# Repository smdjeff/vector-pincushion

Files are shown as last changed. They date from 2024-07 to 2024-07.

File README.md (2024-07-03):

# vector-pincushion

## Allows CRT swaps between various vector game boards and deflection boards. 

Finding tubes for vector arcade displays is difficult and being able to mix and match deflection boards, TV CRTs and arcade PCBs is becoming a necessity. Some arcade games relied on an exact combination of tube shape, yoke, and game board to correctly display.  There may be analog corrections on either the arcade PCB or the deflection board or even the CRT yoke and neck. The Amplifone deflection boards contain no corrections, so when used with a Wells Gardner game PCB adding a correction board is a necessity to add the missing circuity. Tempest PCBs lacked the adjustments as did Sega vectors, but more advanced games like Major Havoc and Star Wars had them on the game boards rather than the deflection boards.

This board allows correction or decorrection as required depending on what you have combined.

### Linearity adjustment 
applies the function _X = X * k_ and _Y = Y * k_ allowing calibration of straightness in diagonally drawn vectors. When set to expansion mode, the correction will cause lines to be drawn further and further outward from the center. When set to shrink mode, the correction will cause lines to be drawn closer and closer the further they are from the center.

### Pincushion correction 
applies the function _X = X * k * Y_ and _Y = Y * k * X_ allowing for each axis to be drawn further or closer toward the center depending on the *opposite* axis distance from center.

## Features

* Barreling correction mode
* Pincushion correction mode
* Linearity shrinking mode
* Linearity expansion mode
* Performs geometric distortion math in analog circuity
* Single 5V supply
* No unobtanium voltage dependent resistor required
* No unobtanium MC1495 analog multipler required
* All new design around the AD633 analog multipler typically used in very high end audio equipment.
* Supports 2x faster speed than orignal when used with TI-H 5.25MHz bandwidth amplifiers.

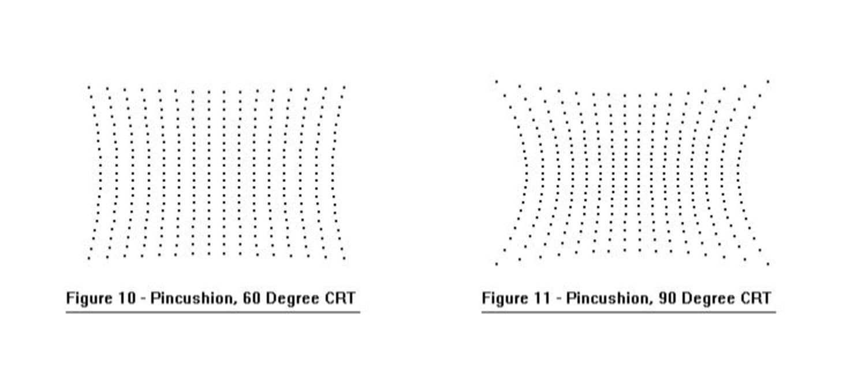
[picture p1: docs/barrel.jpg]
Barrel and Pincushion

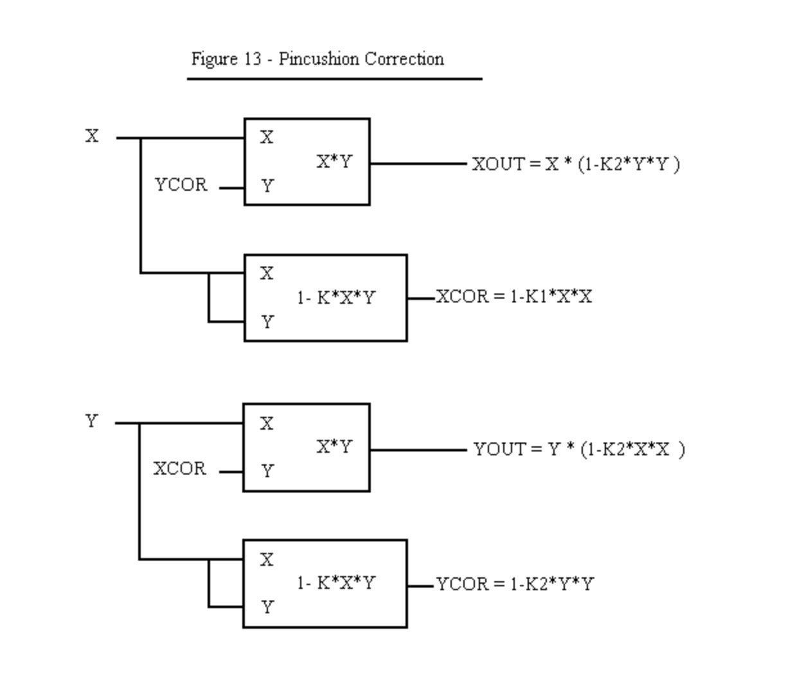
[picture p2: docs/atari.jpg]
Atari Math

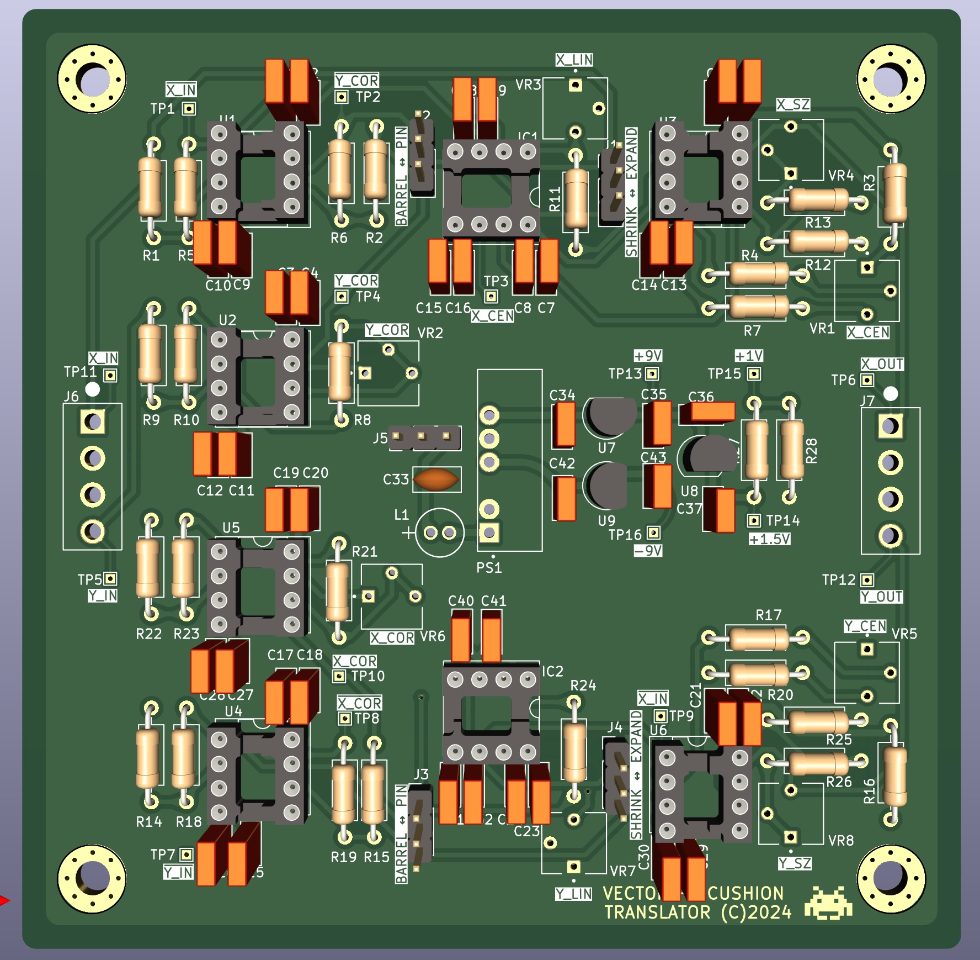
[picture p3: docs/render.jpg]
Board Render


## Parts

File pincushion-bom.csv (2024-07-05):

Qty | Reference(s) | Value | Part Number
20 | C1, C3, C5, C7, C9, C11, C13, C15, C17, C19, C21, C23, C25, C27, C29, C31, C35, C39, C41, C43 | .1uF | K104K15X7RF5TL2
18 | C2, C4, C6, C8, C10, C12, C14, C16, C18, C20, C22, C24, C26, C28, C30, C32, C38, C40 | .01uF | K103K10X7RF53L2
1 | C33 | 10uF CER | FG16X7R1E106KRT06
2 | C34, C42 | .33uF | FA24X7R1H334KNU06
2 | C36, C37 | 1uF | FG28X7R1E105KRT00
2 | IC1, IC2 | AD633JN | AD633JN
5 | J1, J2, J3, J4, J5 | Conn_01x03_Male | DNP
2 | J6, J7 | 640385-4 | WM50027-04-ND
1 | L1 | 22uH | 11R223C
1 | PS1 | RD-0512D | RD-0512D
1 | R28 | 100k 0.1% | RN55E1003BRE6
12 | R1, R2, R4, R5, R6, R9, R14, R15, R17, R18, R19, R22 | 100k 1% | MFR-25FRF52-100K
4 | R3, R7, R16, R20 | 1M | MF0207FRE52-1M
6 | R8, R10, R12, R21, R23, R25 | 10k | MFR-25FRF52-10K
3 | R11, R24, R27 | 50k 0.1% | RN55C5002BB14
2 | R13, R26 | 70k | RN55D7002FB14
6 | U1, U2, U3, U4, U5, U6 | TL082 | TL082CP
1 | U7 | DI78L09ZAB | DI78L09ZAB
1 | U8 | MCP1702-1502E/TO | MCP1702-1502E/TO
1 | U9 | DI79L09ZAB | DI79L09ZAB
2 | VR1, VR5 | 100k | 3362P-1-104LF
2 | VR2, VR6 | 10k | 3362P-1-103LF
4 | VR3, VR4, VR7, VR8 | 20k | 3362P-1-203LF

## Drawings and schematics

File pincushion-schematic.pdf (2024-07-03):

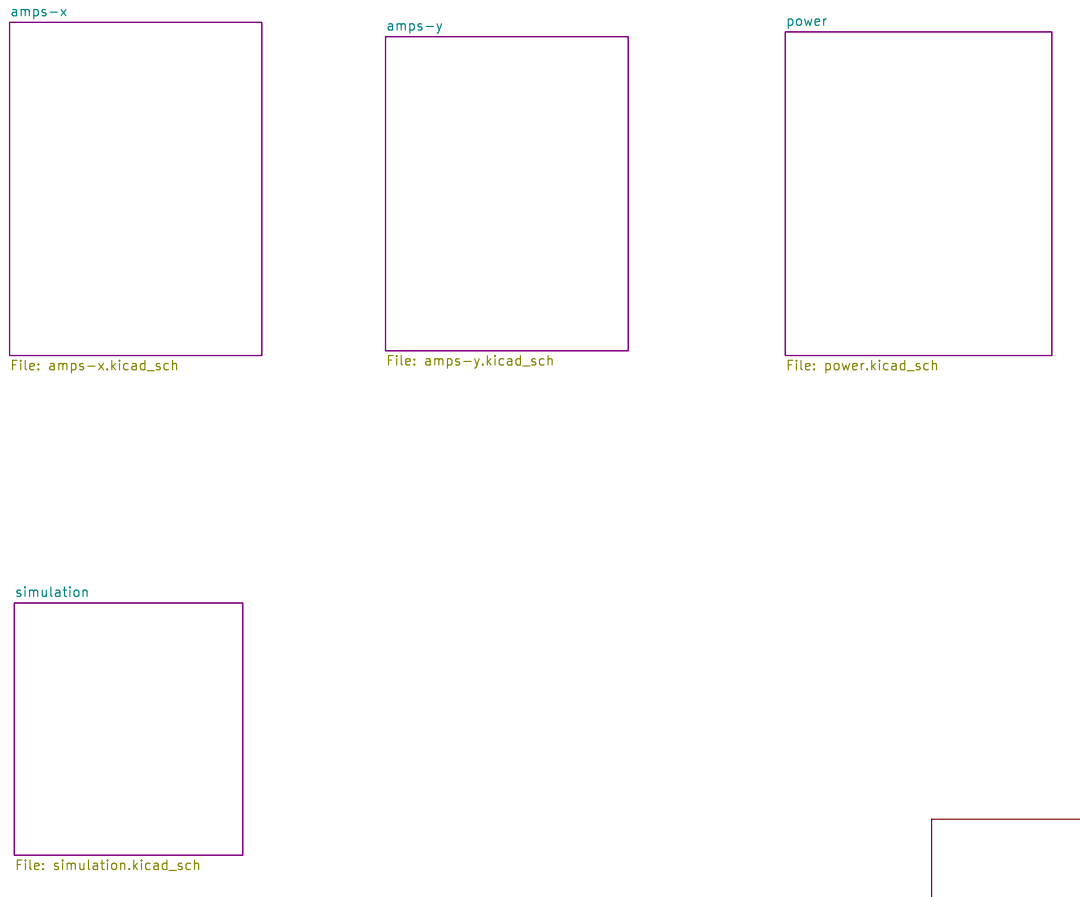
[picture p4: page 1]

Id: 1/5 Title: File: pincushion2.kicad_sch Sheet: / simulation File: simulation.kicad_sch

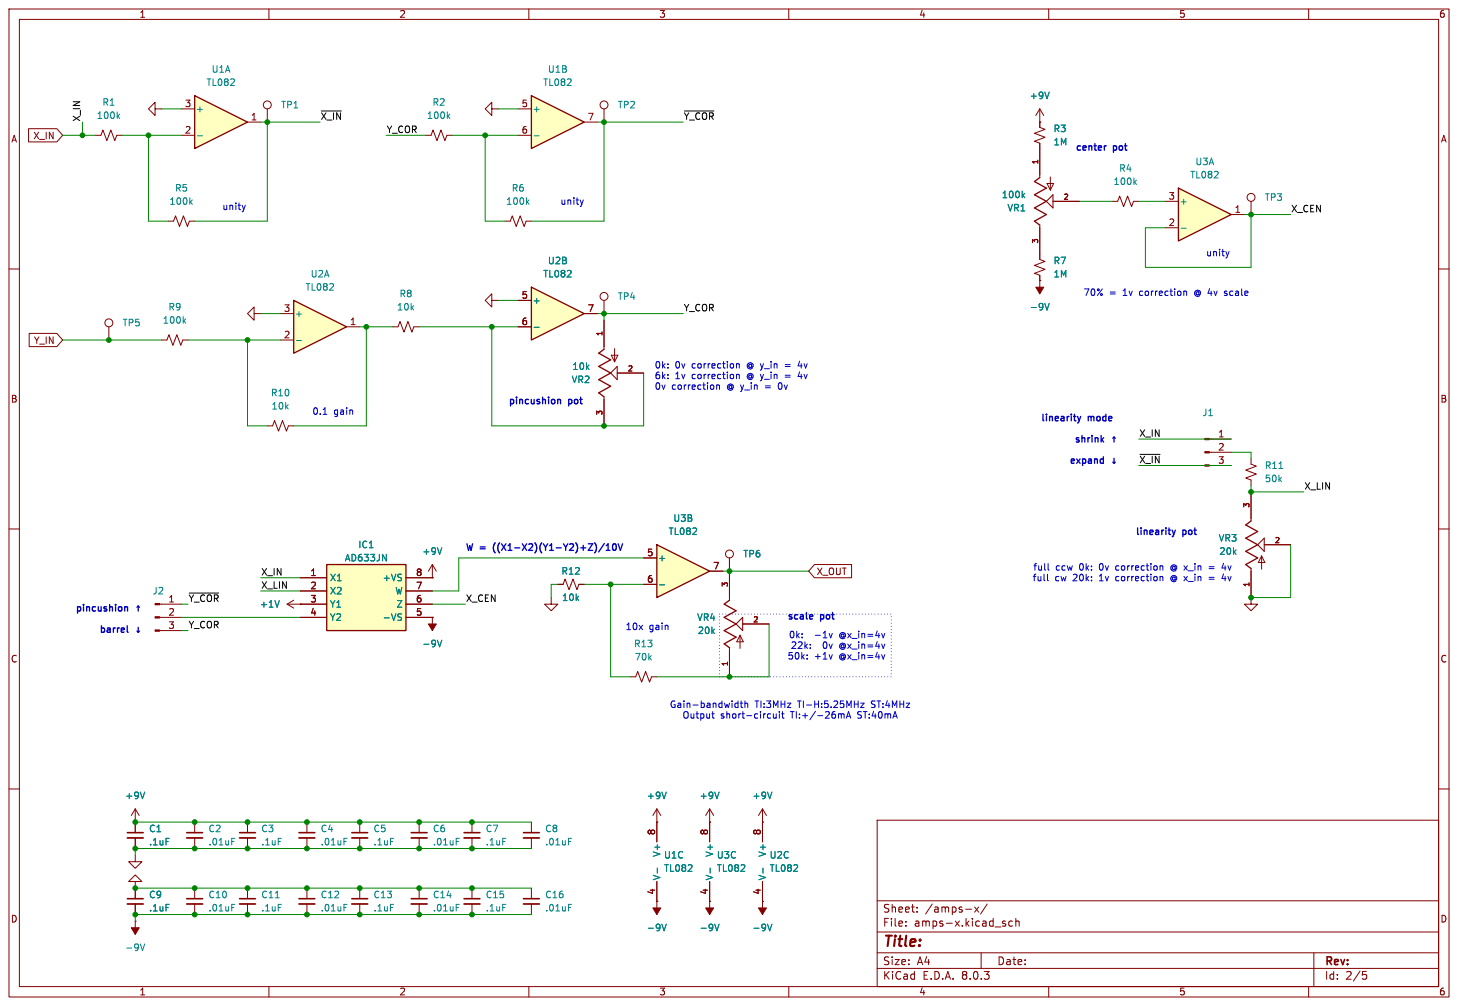
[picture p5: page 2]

Id: 2/5 Title: File: amps-x.kicad_sch Sheet: /amps-x/ V- 4 V+

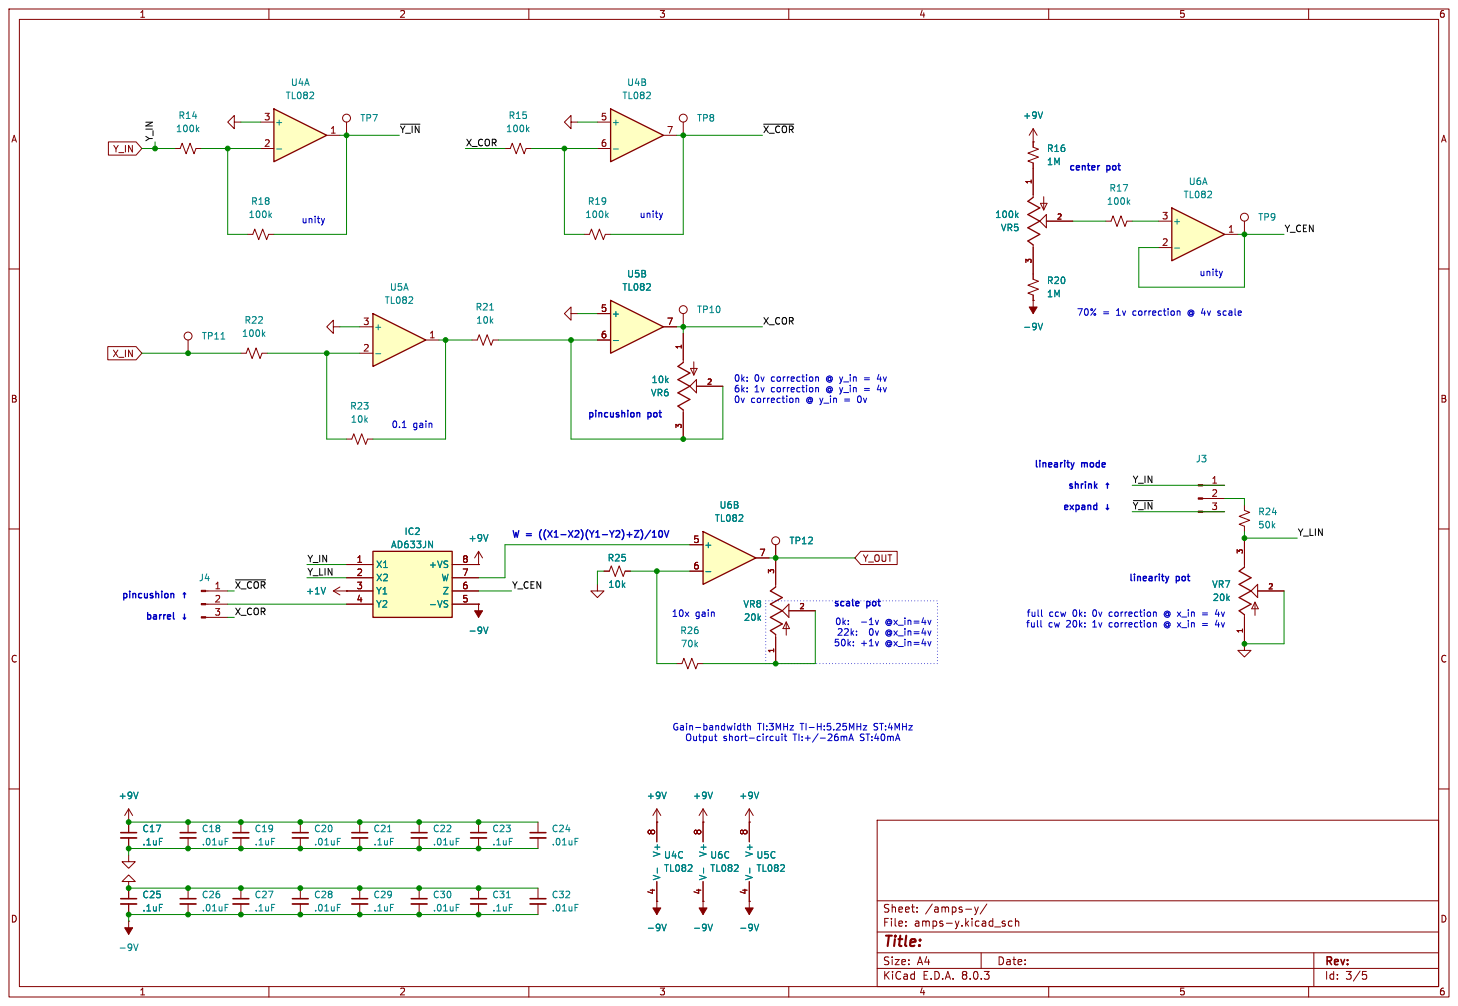
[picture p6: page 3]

Id: 3/5 Title: File: amps-y.kicad_sch Sheet: /amps-y/

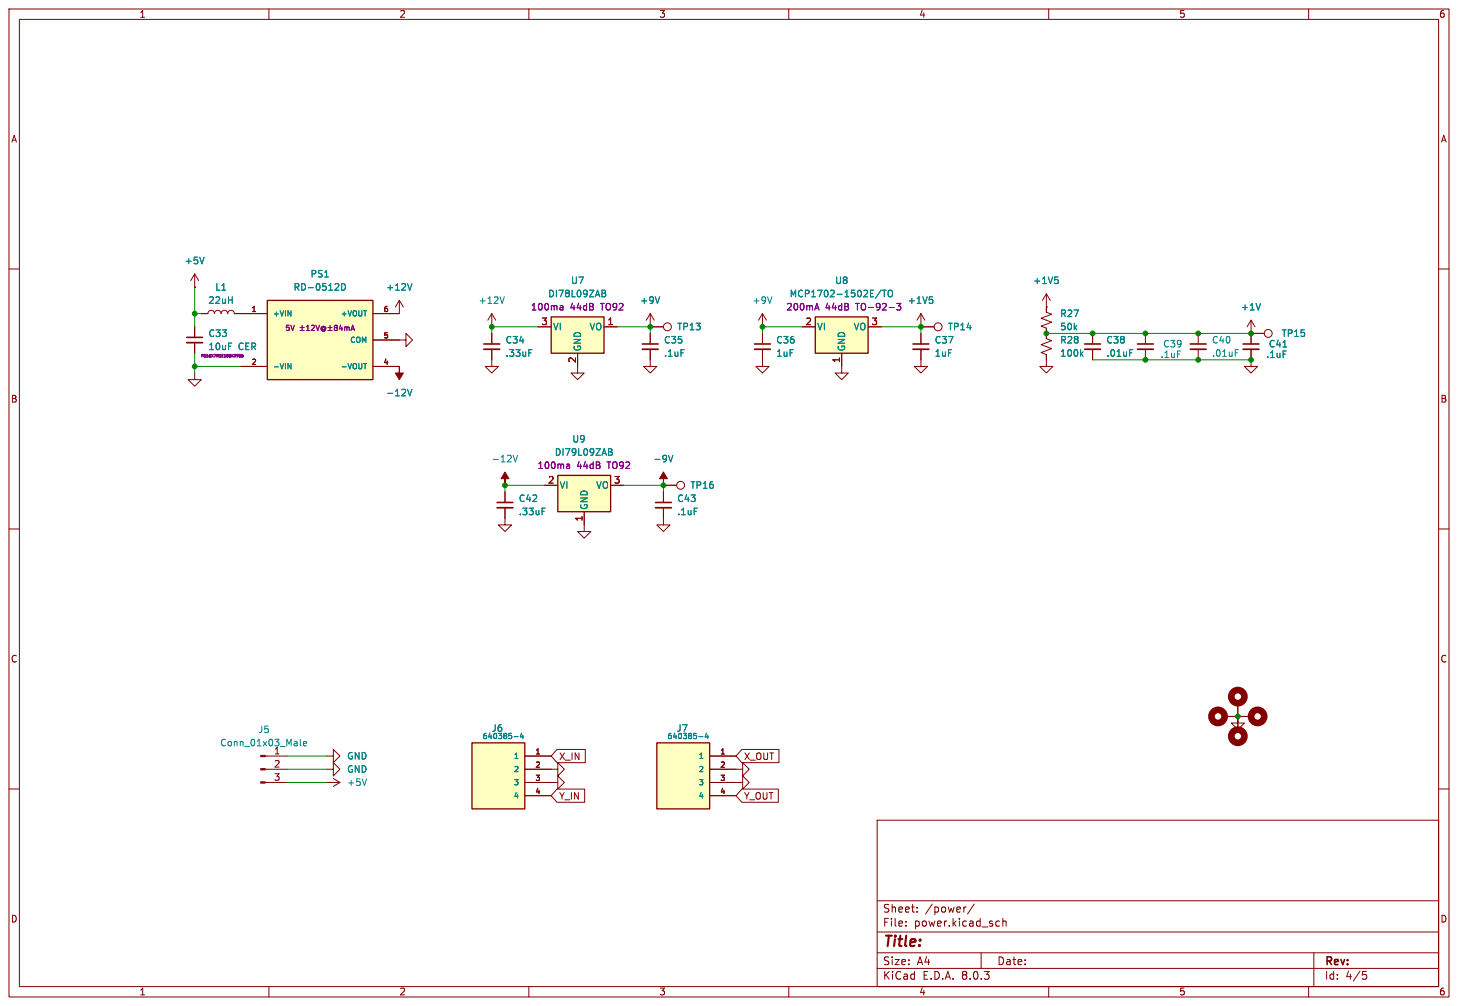
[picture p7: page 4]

Id: 4/5 Title: File: power.kicad_sch Sheet: /power/

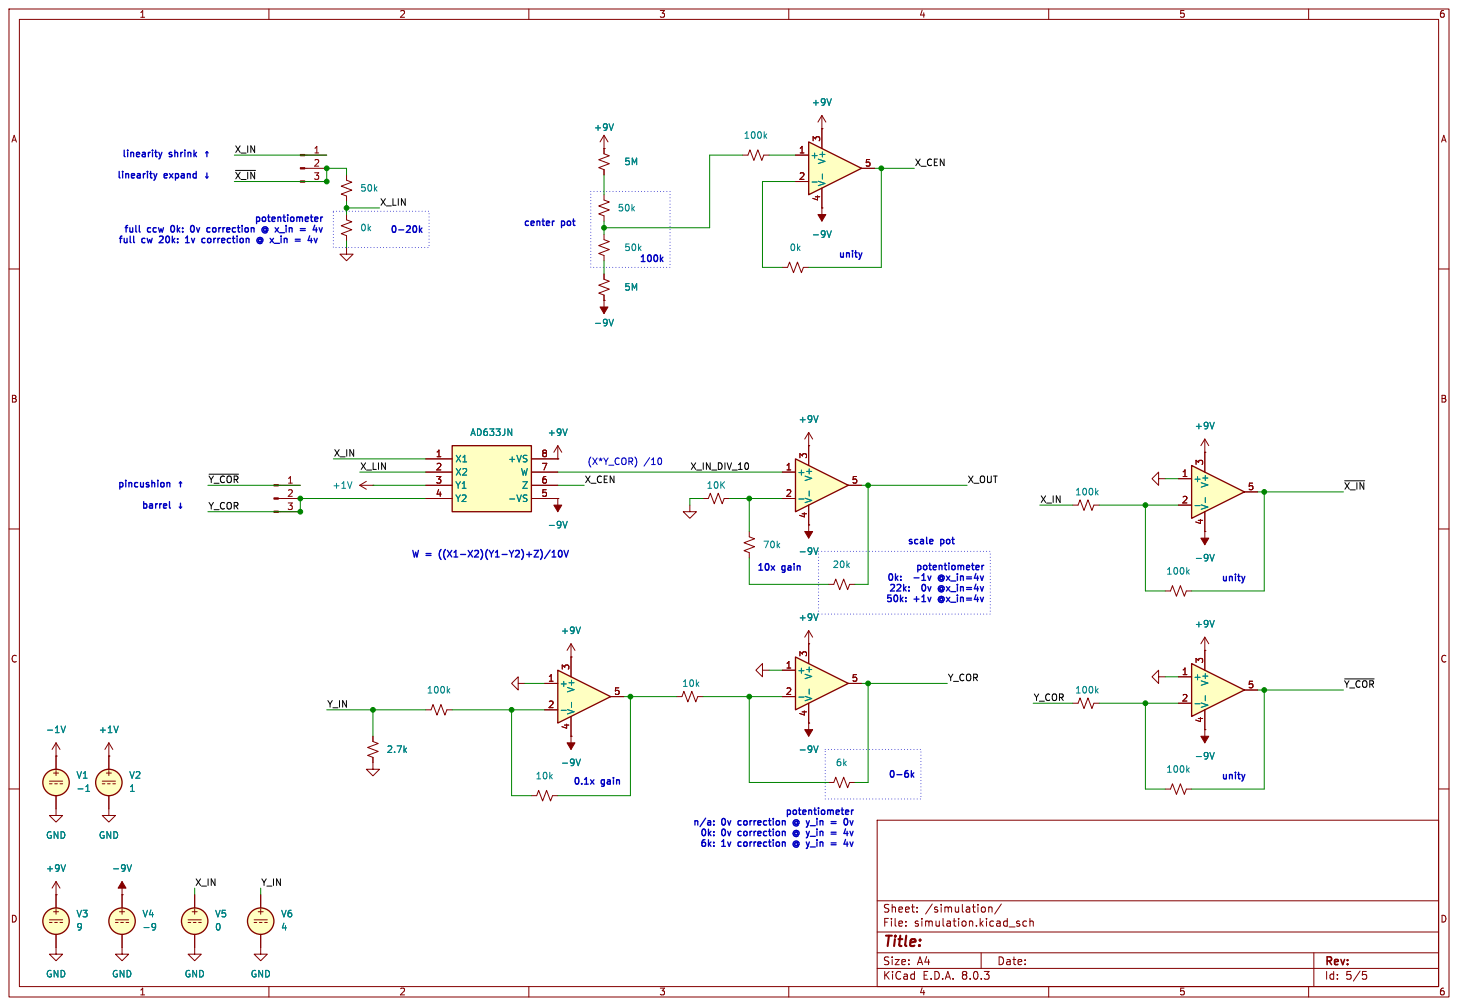
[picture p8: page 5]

full ccw 0k: 0v correction @ x_in = 4v
full cw 20k: 1v correction @ x_in = 4v pincushion þÿ!‘ barrel þÿ!“

Id: 5/5 Title: File: simulation.kicad_sch Sheet: /simulation/ +9V

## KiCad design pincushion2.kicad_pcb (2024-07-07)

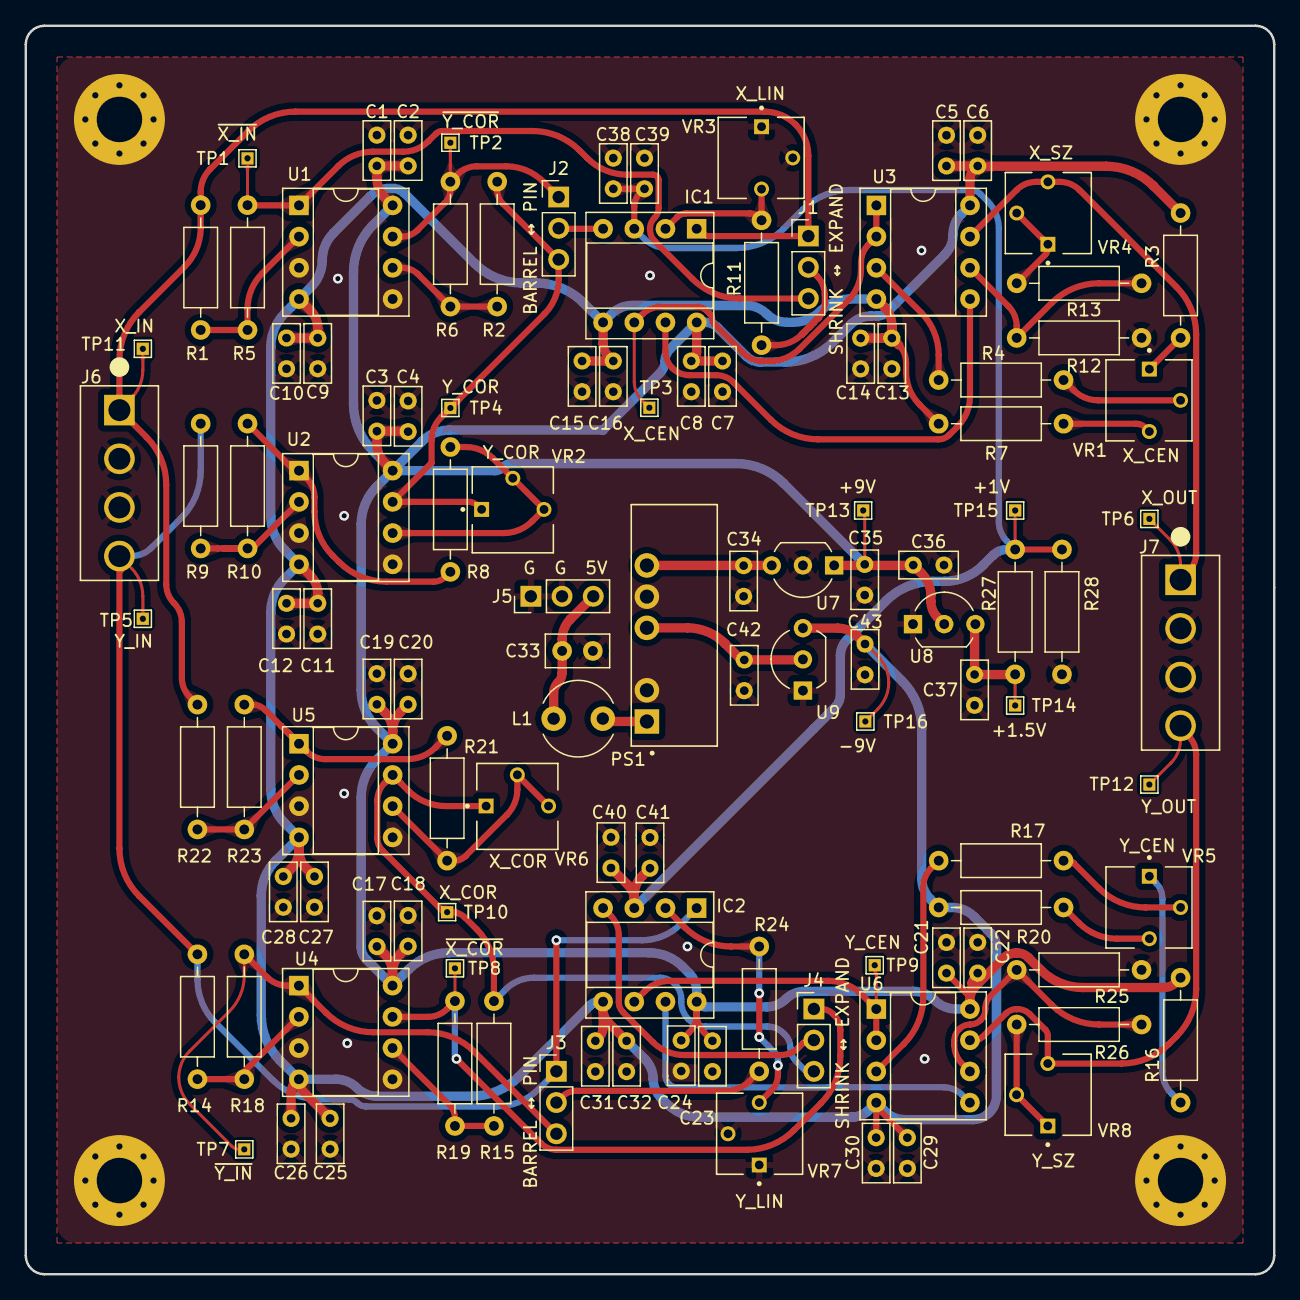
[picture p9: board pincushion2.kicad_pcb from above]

Board: 2 copper layers, 101.6 x 101.6 mm, 119 parts (0 on the bottom side), 51 nets.

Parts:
C1, C3, C5, C7, C9, C11, C13, C15, C17, C19, C21, C23, C25, C27, C29, C31, C35, C39, C41, C43: .1uF; C_Rect_L4.6mm_W2.0mm_P2.50mm_MKS02_FKP02
C2, C4, C6, C8, C10, C12, C14, C16, C18, C20, C22, C24, C26, C28, C30, C32, C38, C40: .01uF; C_Rect_L4.6mm_W2.0mm_P2.50mm_MKS02_FKP02
C33: 10uF CER; C_Disc_D5.0mm_W2.5mm_P2.50mm
C34, C42: .33uF; C_Rect_L4.6mm_W2.0mm_P2.50mm_MKS02_FKP02
C36, C37: 1uF; C_Rect_L4.6mm_W2.0mm_P2.50mm_MKS02_FKP02
H1, H2, H3, H4: MountingHole_Pad; MountingHole_3.7mm_Pad_Via
IC1, IC2: AD633JN; DIP-8_W7.62mm_Socket
J1, J2, J3, J4, J5: Conn_01x03_Male; PinHeader_1x03_P2.54mm_Vertical
J6, J7: 640385-4; TE_640385-4
L1: 22uH; L_Radial_D6.0mm_P4.00mm
PS1: RD-0512D; CONV_RD-0512D
R1, R2, R4, R5, R6, R9, R14, R15, R17, R18, R19, R22, R28: 100k; R_Axial_DIN0207_L6.3mm_D2.5mm_P10.16mm_Horizontal
R3, R7, R16, R20: 1M; R_Axial_DIN0207_L6.3mm_D2.5mm_P10.16mm_Horizontal
R8, R10, R12, R21, R23, R25: 10k; R_Axial_DIN0207_L6.3mm_D2.5mm_P10.16mm_Horizontal
R11, R24, R27: 50k; R_Axial_DIN0207_L6.3mm_D2.5mm_P10.16mm_Horizontal
R13, R26: 70k; R_Axial_DIN0207_L6.3mm_D2.5mm_P10.16mm_Horizontal
TP1, TP2, TP3, TP4, TP5, TP6, TP7, TP8, TP9, TP10, TP11, TP12, TP13, TP14, TP15, TP16: TestPoint; TestPoint_THTPad_1.0x1.0mm_Drill0.5mm
U1, U2, U3, U4, U5, U6: TL082; DIP-8_W7.62mm_Socket
U7: DI78L09ZAB; TO-92_Inline_Wide
U8: MCP1702-1502E/TO; TO-92_Inline_Wide
U9: DI79L09ZAB; TO-92_Inline_Wide
VR1, VR5: 100k; TRIM_3362P-1-103LF
VR2, VR6: 10k; TRIM_3362P-1-103LF
VR3, VR4, VR7, VR8: 20k; TRIM_3362P-1-103LF

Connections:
+1V: C38.1, C39.1, C40.1, C41.1, IC1.3 (Y1), IC2.3 (Y1), R27.1, R28.2, TP15.1
+1V5: C37.1, R27.2, TP14.1, U8.3 (VO)
+5V: C33.1, J5.3, L1.1
+9V: C1.1, C2.1, C3.1, C4.1, C5.1, C6.1, C7.1, C8.1, C17.1, C18.1, C19.1, C20.1, C21.1, C22.1, C23.1, C24.1, C35.1, C36.1, IC1.8 (+VS), IC2.8 (+VS), R3.2, R16.2, TP13.1, U1.8 (V+), U2.8 (V+), U3.8 (V+), U4.8 (V+), U5.8 (V+), U6.8 (V+), U7.1 (VO), U8.2 (VI)
+12V: C34.1, PS1.6 (+VOUT), U7.3 (VI)
-9V: C9.2, C10.2, C11.2, C12.2, C13.2, C14.2, C15.2, C16.2, C25.2, C26.2, C27.2, C28.2, C29.2, C30.2, C31.2, C32.2, C43.1, IC1.5 (-VS), IC2.5 (-VS), R7.1, R20.1, TP16.1, U1.4 (V-), U2.4 (V-), U3.4 (V-), U4.4 (V-), U5.4 (V-), U6.4 (V-), U9.3 (VO)
-12V: C42.1, PS1.4 (-VOUT), U9.2 (VI)
/amps-x/X_CEN: IC1.6 (Z), TP3.1, U3.1, U3.2 (-)
/amps-x/X_LIN: IC1.2 (X2), R11.1, VR3.3
/amps-x/Y_COR: J2.3, R2.1, TP4.1, U2.7, VR2.1
/amps-x/~X_IN: J1.3, R5.2, TP1.1, U1.1
/amps-x/~Y_COR: J2.1, R6.2, TP2.1, U1.7
/amps-y/X_COR: J4.3, R15.1, TP10.1, U5.7, VR6.1
/amps-y/Y_CEN: IC2.6 (Z), TP9.1, U6.1, U6.2 (-)
/amps-y/Y_LIN: IC2.2 (X2), R24.1, VR7.3
/amps-y/~X_COR: J4.1, R19.2, TP8.1, U4.7
/amps-y/~Y_IN: J3.3, R18.2, TP7.1, U4.1
GND: C1.2, C2.2, C3.2, C4.2, C5.2, C6.2, C7.2, C8.2, C9.1, C10.1, C11.1, C12.1, C13.1, C14.1, C15.1, C16.1, C17.2, C18.2, C19.2, C20.2, C21.2, C22.2, C23.2, C24.2, C25.1, C26.1, C27.1, C28.1, C29.1, C30.1, C31.1, C32.1, C33.2, C34.2, C35.2, C36.2, C37.2, C38.2, C39.2, C40.2, C41.2, C42.2, C43.2, H1.1, H2.1, H3.1, H4.1, J5.1, J5.2, J6.2, J6.3, J7.2, J7.3, PS1.2 (-VIN), PS1.5 (COM), R12.1, R25.1, R28.1, U1.3 (+), U1.5 (+), U2.3 (+), U2.5 (+), U4.3 (+), U4.5 (+), U5.3 (+), U5.5 (+), U7.2 (GND), U8.1 (GND), U9.1 (GND), VR3.1, VR3.2, VR7.1, VR7.2
unnamed: IC1.7 (W), U3.5 (+)
unnamed: IC1.4 (Y2), J2.2
unnamed: IC2.7 (W), U6.5 (+)
unnamed: IC2.4 (Y2), J4.2
unnamed: J1.2, R11.2
unnamed: J3.2, R24.2
unnamed: L1.2, PS1.1 (+VIN)
unnamed: R3.1, VR1.1
unnamed: R4.1, VR1.2
unnamed: R7.2, VR1.3
unnamed: R8.1, R10.2, U2.1
unnamed: R13.2, VR4.1, VR4.2
unnamed: R16.1, VR5.1
unnamed: R17.1, VR5.2
unnamed: R20.2, VR5.3
unnamed: R21.1, R23.2, U5.1
unnamed: R26.2, VR8.1, VR8.2
unnamed: R1.2, R5.1, U1.2 (-)
unnamed: R2.2, R6.1, U1.6 (-)
unnamed: R9.2, R10.1, U2.2 (-)
unnamed: R8.2, U2.6 (-), VR2.2, VR2.3
unnamed: R4.2, U3.3 (+)
unnamed: R12.2, R13.1, U3.6 (-)
unnamed: R14.2, R18.1, U4.2 (-)
unnamed: R15.2, R19.1, U4.6 (-)
unnamed: R22.2, R23.1, U5.2 (-)
unnamed: R21.2, U5.6 (-), VR6.2, VR6.3
unnamed: R17.2, U6.3 (+)
unnamed: R25.2, R26.1, U6.6 (-)
X_IN: IC1.1 (X1), J1.1, J6.1, R1.1, R22.1, TP11.1
X_OUT: J7.1, TP6.1, U3.7, VR4.3
Y_IN: IC2.1 (X1), J3.1, J6.4, R9.1, R14.1, TP5.1
Y_OUT: J7.4, TP12.1, U6.7, VR8.3

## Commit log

2024-07-04 correct silkscreen
    [pincushion2-B_Cu.gbr, pincushion2-B_Mask.gbr, pincushion2-B_Paste.gbr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]
2024-07-04 move input connector so board can stack with the sega-amplifone board
    [pincushion2-B_Cu.gbr, pincushion2-B_Mask.gbr, pincushion2-B_Paste.gbr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]
2024-07-05 add bom
    [pincushion-bom.csv]
2024-07-07 add thermals to caps and resistors. more pitch spacing for inductor and TO92 packages.
    [pincushion2-B_Cu.gbr, pincushion2-B_Mask.gbr, pincushion2-B_Paste.gbr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]

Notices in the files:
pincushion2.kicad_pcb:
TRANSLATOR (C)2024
